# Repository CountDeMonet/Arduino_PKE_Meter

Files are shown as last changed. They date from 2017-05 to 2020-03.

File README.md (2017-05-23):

# Arduino_PKE_Meter
Code and models for an arduino based Ghostbusters PKE Meter

GBFans thread: http://www.gbfans.com/forum/viewtopic.php?f=5&t=43258

Video of how the meter looks when finished

https://www.youtube.com/watch?v=xTfZLYqommg

I have also included the eagle cad files that I used to produce an LED board for this project. OshPark is an amazing place to get custom PCB's fabricated and they will take the brd file as is. I ended up using a buck converter to power the servo so the path with the capacitor was no longer needed. That saved some space but the board was already in fab. 

Image of the internals
https://i1.wp.com/vineripesoftware.files.wordpress.com/2017/05/img_20170508_222438829.jpg

I recommend using hitec servo wire if you can get your hands on it for the wings. I printed everything at .3mm resolution with 20% infill. This print requires a lot of support and there is no way around it.

It's based off this model on Thingiverse (https://www.thingiverse.com/thing:700251) I scaled it up to 110%, removed a few buttons to make it easier to use for my son, and created a new battery holder for the 4 AAA's that power it. I decided on an Arduino nano as the brains with a cheap LCD for display. Again, not going for screen accurate but something that will keep a 6-7 year old entertained. I did program in the Ghostbusters 2 LED pattern for the wings.

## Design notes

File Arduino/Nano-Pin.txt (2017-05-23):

vin/gnd - to power
5v/gnd - to rail
A4 - SDA on Display
A5 - SLC on Display
D3 - Button 1
D4 - Button 2
D5 - Buzzer
D6 - LED 1
D7 - LED 2
D8 - LED 3
D9 - LED 4
D10 - LED 5
D11 - LED 6
D12 - LED 7
D13 - Servo Signal

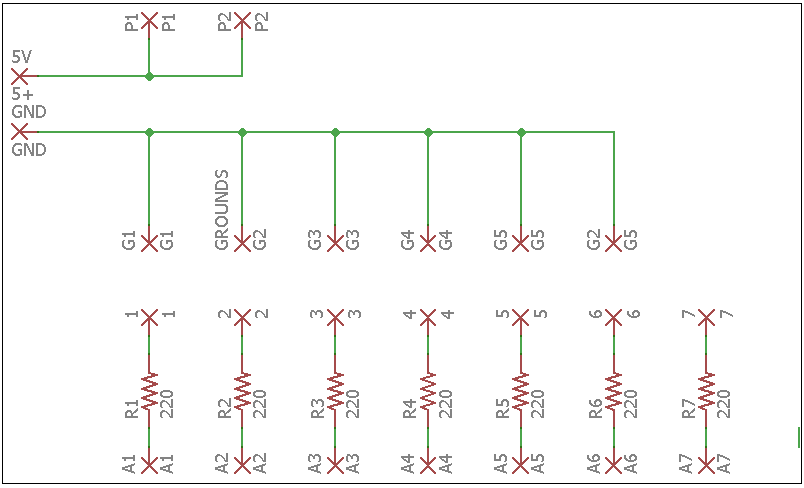
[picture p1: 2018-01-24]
Eagle/schematic.png

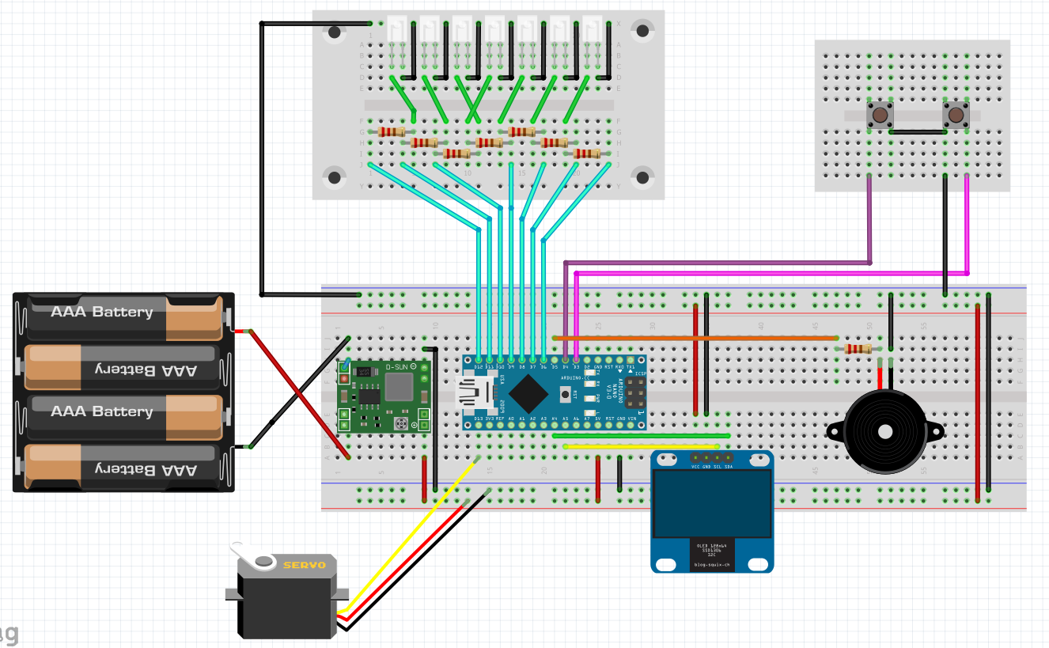
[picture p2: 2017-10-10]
PKE_Meter_Breadboard.png

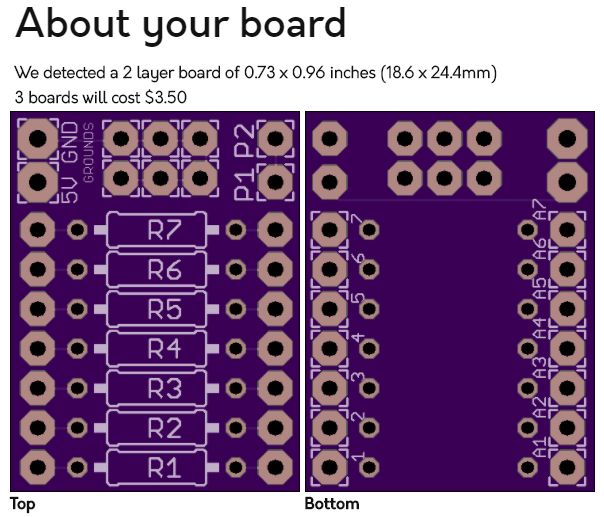
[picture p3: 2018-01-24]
Eagle/layout.png

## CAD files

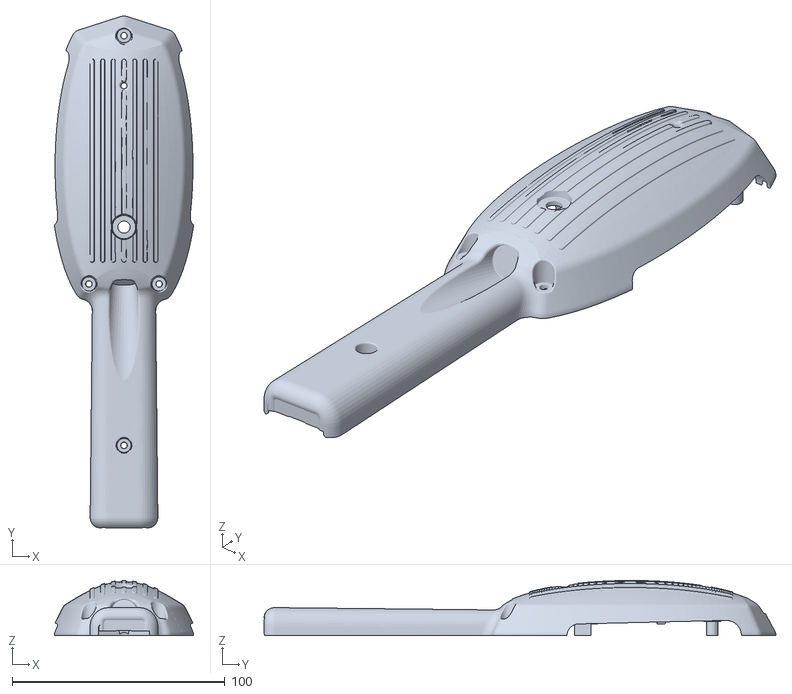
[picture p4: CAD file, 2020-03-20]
Model/back_one_piece.stl
65.5 x 240.6 x 25.9

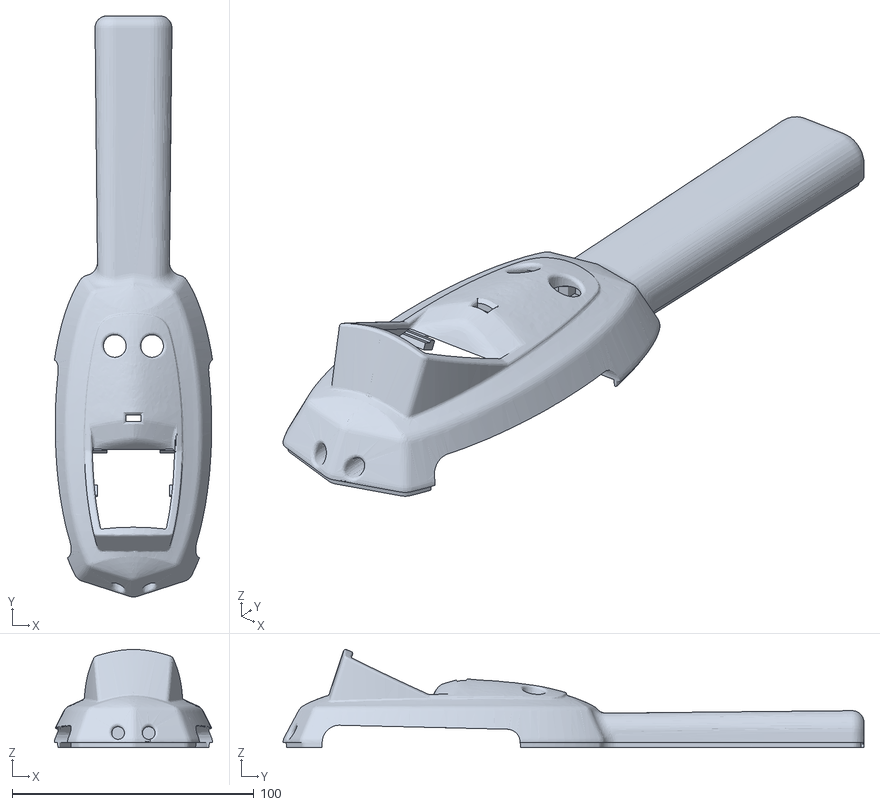
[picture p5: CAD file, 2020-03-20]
Model/front_one_piece.stl
65.5 x 240.5 x 40.6

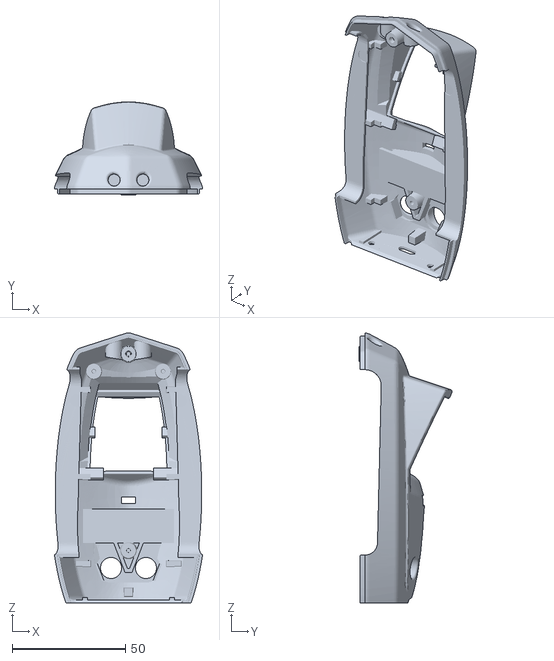
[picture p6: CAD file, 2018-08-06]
Model/front_top.stl
65.5 x 41.3 x 119.4

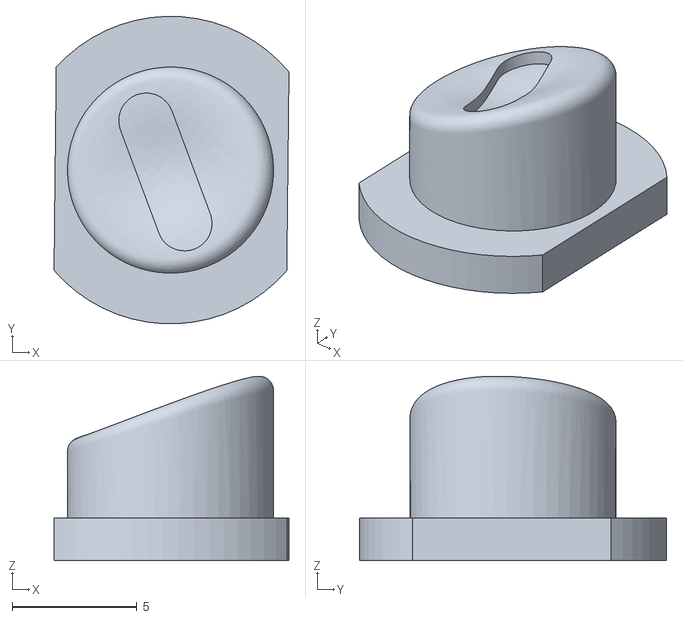
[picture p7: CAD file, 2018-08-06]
Model/buttons_filled.stl
9.41 x 12.3 x 7.39

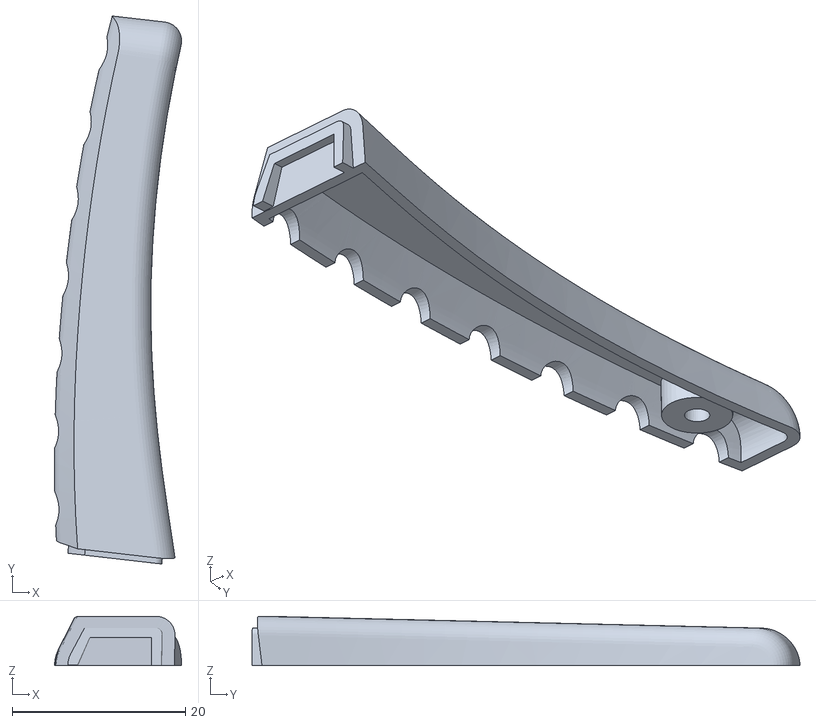
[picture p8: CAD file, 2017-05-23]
Model/wings_cover_right.stl
14.7 x 63.3 x 5.71

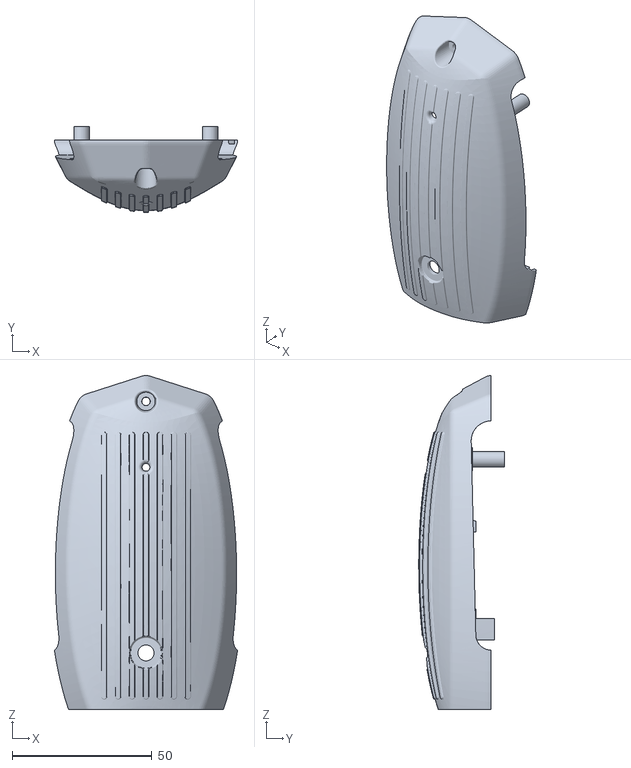
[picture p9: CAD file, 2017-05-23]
Model/back_top.stl
65.5 x 30.6 x 119.4

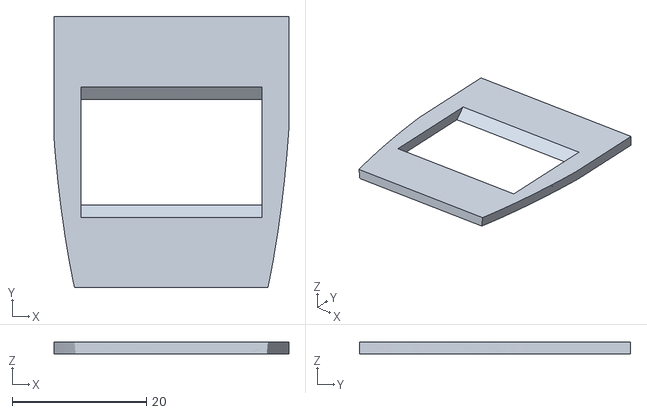
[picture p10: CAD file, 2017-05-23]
Model/screen_holder.stl
35.0 x 40.3 x 1.86

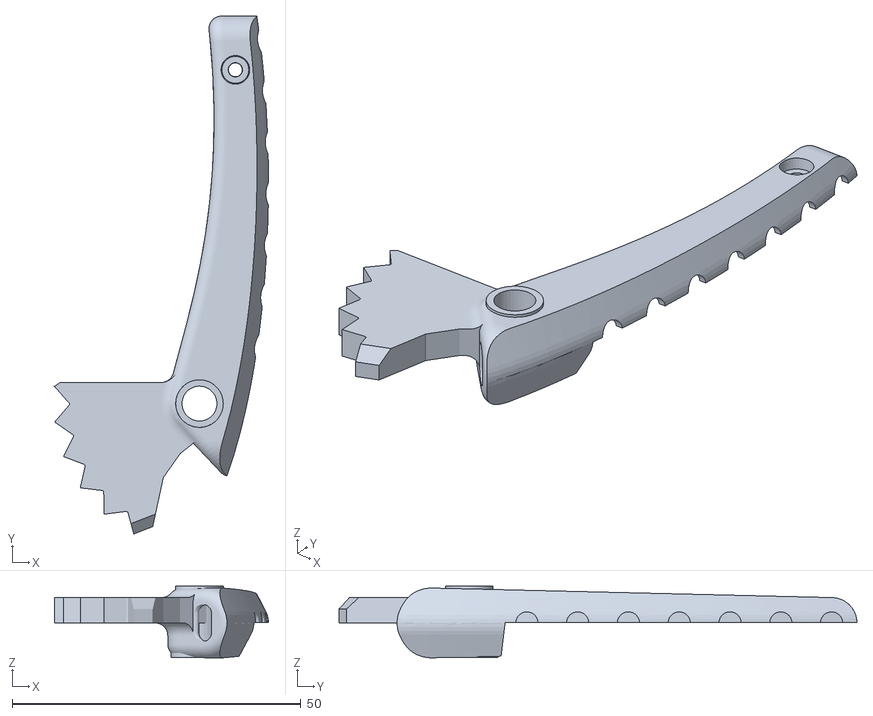
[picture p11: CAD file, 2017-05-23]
Model/wings_right.stl
37.1 x 89.8 x 12.4

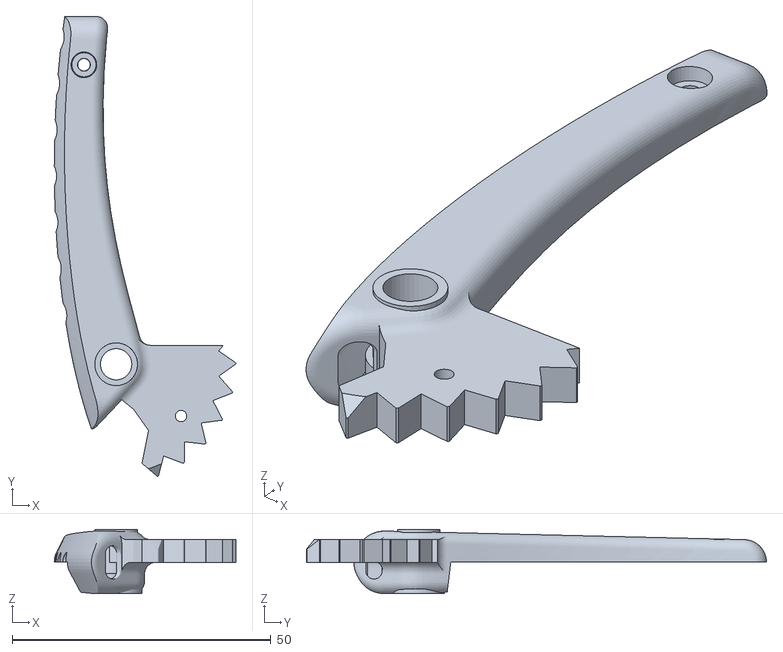
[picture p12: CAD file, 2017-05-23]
Model/wings_left.stl
35.1 x 88.8 x 12.4

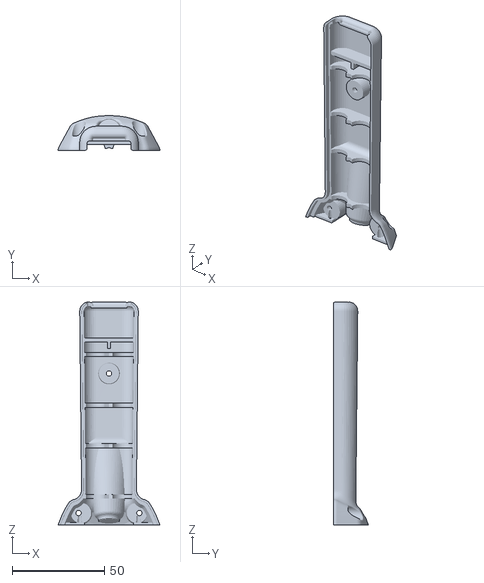
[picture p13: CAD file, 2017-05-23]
Model/back_bottom.stl
55.3 x 18.9 x 121.2

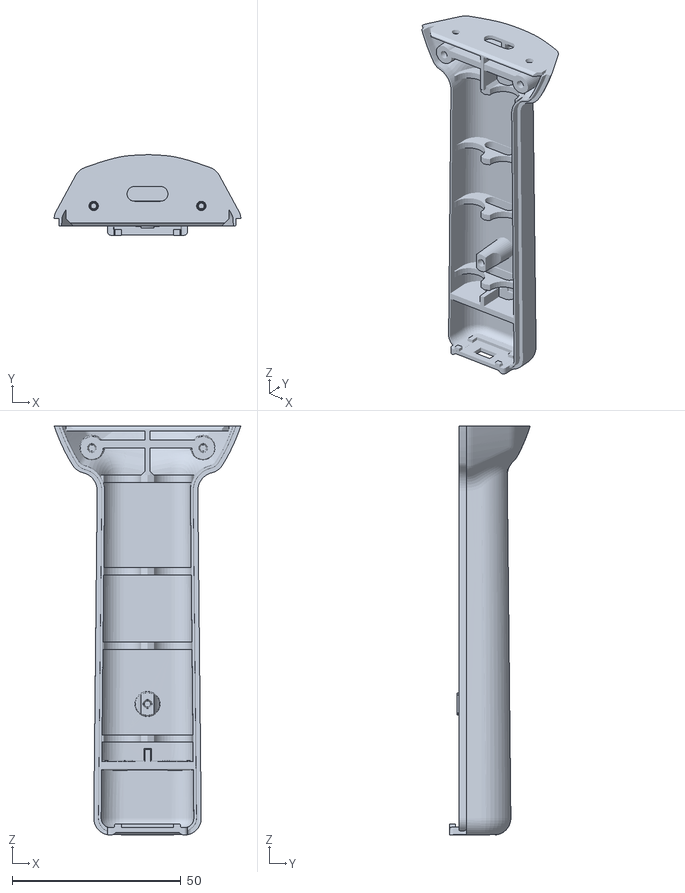
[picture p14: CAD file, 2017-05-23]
Model/front_bottom.stl
55.3 x 23.9 x 121.2

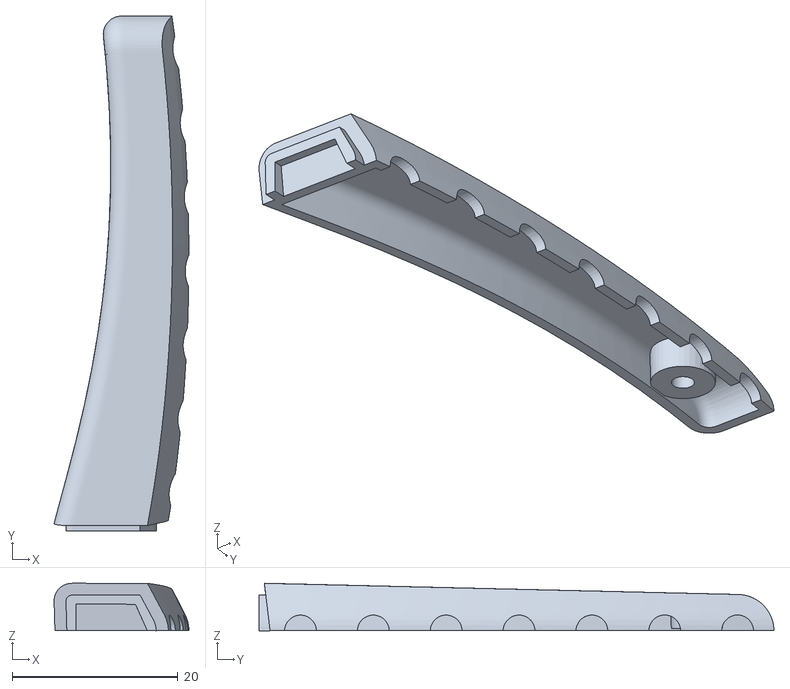
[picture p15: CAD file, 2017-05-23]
Model/wings_cover_left.stl
16.3 x 62.2 x 5.74

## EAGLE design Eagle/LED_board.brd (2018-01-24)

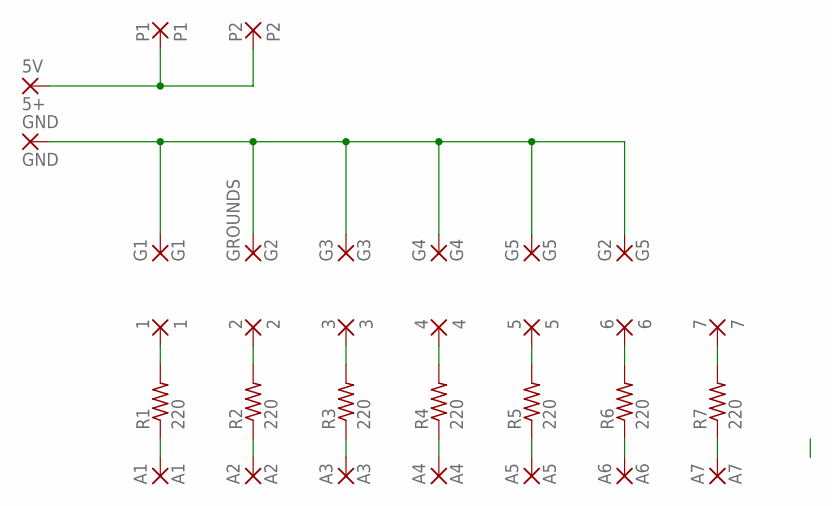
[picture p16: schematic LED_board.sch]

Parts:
1: 1; 2,15/1,0
2: 2; 2,15/1,0
3: 3; 2,15/1,0
4: 4; 2,15/1,0
5: 5; 2,15/1,0
5V: 5+; 2,54/1,1
6: 6; 2,15/1,0
7: 7; 2,15/1,0
A1: A1; 2,15/1,0
A2: A2; 2,15/1,0
A3: A3; 2,15/1,0
A4: A4; 2,15/1,0
A5: A5; 2,15/1,0
A6: A6; 2,15/1,0
A7: A7; 2,15/1,0
G1: G1; 2,15/1,0
G2, G5: G5; 2,15/1,0
G3: G3; 2,15/1,0
G4: G4; 2,15/1,0
GND: GND; 2,54/1,1
GROUNDS: G2; 2,15/1,0
P1: P1; 2,15/1,0
P2: P2; 2,15/1,0
R1, R2, R3, R4, R5, R6, R7: 220; 0207/10

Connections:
unnamed: 5V.1, P1.1, P2.1
unnamed: 1.1, R1.2
unnamed: A1.1, R1.1
unnamed: G1.1, G2.1, G3.1, G4.1, G5.1, GND.1, GROUNDS.1
unnamed: 2.1, R2.2
unnamed: A2.1, R2.1
unnamed: A3.1, R3.1
unnamed: 3.1, R3.2
unnamed: 4.1, R4.2
unnamed: A4.1, R4.1
unnamed: A5.1, R5.1
unnamed: 5.1, R5.2
unnamed: 6.1, R6.2
unnamed: A6.1, R6.1
unnamed: A7.1, R7.1
unnamed: 7.1, R7.2

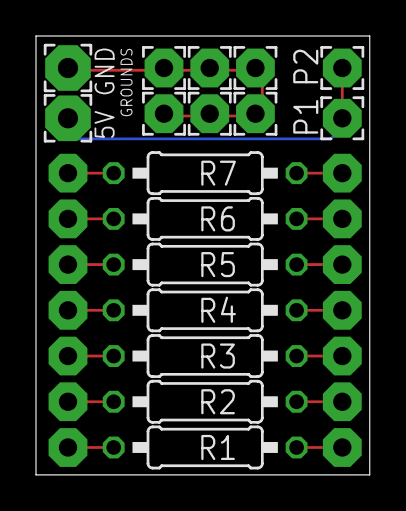
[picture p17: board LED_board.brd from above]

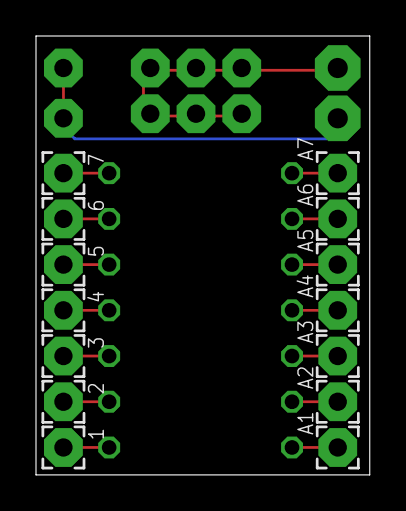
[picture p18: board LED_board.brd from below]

Board: 2 copper layers, 18.5 x 24.4 mm, 31 parts (14 on the bottom side), 16 nets.

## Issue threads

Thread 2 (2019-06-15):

OLED Image Scale Issue

MrBull-STR, 2019-06-15:
SEE Photo for reference.
The image appears
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
 to be scaled to fit another screen than 128x64.

CountDeMonet, 2019-06-17:
a user on gbfans is having the same issue. Are you using the library version that I have in the git repo here?

https://github.com/CountDeMonet/Arduino_PKE_Meter/tree/master/Arduino/libraries

The user on gbfans bought this led screen which the company seems to have designed their own library for. The docs say it works with the lib I use but who knows.

https://www.amazon.ca/gp/product/B01N78FUH7/ref=ppx_yo_dt_b_asin_title_o05_s00?ie=UTF8&psc=1

You may have to use their libs for things to work correctly. Try the adafruit example included in the arduino ide for the SSD1306

File -> Exampes -> Adadfruit SSD1306 -> ssd1306_128x64_ic2

if that one doesn't work properly then you'll have to do some work to figure out what's going on

CountDeMonet, 2019-07-17:
Seems this is coming up more often. DIYMall has a version of this display that appears to have a different resolution so some modifications and possibly use their library version.

This is from a doc linked from the diymall website

http://www.diymalls.com/IIC-OLED-SSD1306
https://drive.google.com/open?id=1qkexP ... 4F-JEKkrHZ

that document zip contains special versions of the adafruit libs
For 0.96 inch: 0.96 inch use SSD1306 drive chip. Copy "Adafruit_SSD1306.h" and
"Adafruit_GFX.h" into "x:\arduino-1.X.X\libraries".
In order to reduce the pins’ number, we use a hardware RESET system. So the
standard library form Adafruit or u8glib may not very suitable. Make sure you are
using our provided libraries, It’s very important. If those files already in you
libraries, replace it.
They also note
The dot matrix is 128 * 32
We never produced any 0.96 or 1.3 inch with 128*32 dot matrix. Open
“Adafruit_SSD1306.h”, and make sure the “#define SSD1306_128_64” is available.
Could be why you are seeing some strange things.

Closed 2020-02-02.

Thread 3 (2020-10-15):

Please add BOM

DarthBanana, 2020-10-15:
It would be great if you could add the bill of materials (parts list).

CountDeMonet, 2020-10-15:
Check the gbfans thread. it has all the info https://www.gbfans.com/forum/viewtopic.php?p=4893554#p4893554

DarthBanana, 2020-10-15:
Thanks for the quick reply!  That is very helpful.

________________________________
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

DarthBanana, 2020-10-15:
What about the battery contact plates?

CountDeMonet, 2020-10-15:
I don't really have a part for that. I think I scavenged something from one of my son's toys.

Closed 2020-10-25.

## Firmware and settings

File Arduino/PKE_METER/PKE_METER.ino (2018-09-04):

#include <Servo.h>
#include <Adafruit_GFX.h>
#include <Adafruit_SSD1306.h>

#define OLED_RESET 4
Adafruit_SSD1306 display(OLED_RESET);

Servo SERVO1;

int LEDNum = 0; // current LED that is lit
unsigned long previousMillis;   // will store last time LED was updated

const int LED1 = 12;
const int LED2 = 11;
const int LED3 = 10;
const int LED4 = 9;
const int LED5 = 8;
const int LED6 = 7;
const int LED7 = 6;

int FILM;
bool SOUND;

const int GB1_PATTERN[7] = {
  LED3, LED5, LED7, LED4, LED1, LED6, LED2
};
const int GB2_PATTERN[7] = {
  LED3, LED1, LED6, LED4, LED7, LED5, LED2
};

const int DISPLAY_PATTERN[][2] = {
  {21, 5},
  {18, 20},
  {15, 30},
  {12, 45},
  {9, 50},
  {6, 55},
  {3, 65}
};

const int BUZZER = 5;
const int BUTTON1 = 3;
const int BUTTON2 = 4;

// know thy button state
bool medium_state = false;
bool high_state = false;
bool button1_down = false;
bool button2_down = false;

void setup() {
  pinMode(LED1, OUTPUT);
  pinMode(LED2, OUTPUT);
  pinMode(LED3, OUTPUT);
  pinMode(LED4, OUTPUT);
  pinMode(LED5, OUTPUT);
  pinMode(LED6, OUTPUT);
  pinMode(LED7, OUTPUT);
  pinMode(BUZZER, OUTPUT);
  pinMode(BUTTON1, INPUT);
  pinMode(BUTTON2, INPUT);

  digitalWrite(BUTTON1, HIGH);
  digitalWrite(BUTTON2, HIGH);

  // The following lines are because my PKE setup
  // is currently running without the buck converter.
  // Pin D2 acts as VCC for the OLED screen
  // PN June 12, 2018d
  pinMode(2, OUTPUT);
  digitalWrite(2, HIGH);

  display.begin(SSD1306_SWITCHCAPVCC, 0x3C);
  display.display();

  // Clear the buffer.
  display.clearDisplay();
  initialSetup();

  SERVO1.attach(13);
  SERVO1.write(90);
}

// current display val
int currentVal = 0;
void loop() {
  int button1 = digitalRead(BUTTON1);
  int button2 = digitalRead(BUTTON2);

  if ( button1 == LOW && button1_down == false ) {
    button1_down = true;

    if ( medium_state == true) {
      medium_state = false;
      high_state = false;
      currentVal = 0;
    } else {
      medium_state = true;
      high_state = false;
      currentVal = 40;
    }
  } else {
    if (button1 == HIGH && button1_down == true ) {
      button1_down = false;
    }
  }

  if ( button2 == LOW && button2_down == false ) {
    button2_down = true;

    if (high_state == true) {
      medium_state = false;
      high_state = false;
      currentVal = 0;
    } else {
      medium_state = false;
      high_state = true;
      currentVal = 90;
    }
  } else {
    if (button2 == HIGH && button2_down == true ) {
      button2_down = false;
    }
  }

  // do the led stuff
  LEDLoop(currentVal);

  // do the servo stuff
  ServoLoop(currentVal);

  // delay in between reads for stability
  delay(1);
}

void initialSetup(){
  String headings[] = {"WHICH PATTERN?", "SOUNDS?"};
  String labels[][2] = {
    {"GB1", "GB2"},
    {"NO", "YES"}
  };
  for (int i = 0; i < 2; i++){
    int button1 = digitalRead(BUTTON1);
    int button2 = digitalRead(BUTTON2);
    while (button1 == HIGH && button2 == HIGH){
      display.setTextSize(1);
      display.setTextColor(WHITE);
      display.setCursor(22, 5);
      display.print(headings[i]);
      display.setCursor(10, 30);
      display.print(labels[i][0]);
      display.setCursor(100, 30);
      display.print(labels[i][1]);
      display.display();
      button1 = digitalRead(BUTTON1);
      button2 = digitalRead(BUTTON2);
    }
    if (button1 == LOW && i == 0){
      FILM = 1;
    } else if (button2 == LOW && i == 0){
      FILM = 2;
    } else if (button1 == LOW && i == 1) {
      SOUND = false;
    } else if (button2 == LOW && i == 1) {
      SOUND = true;
    }
    digitalWrite(BUTTON1, HIGH);
    digitalWrite(BUTTON2, HIGH);
    delay(500);
    display.clearDisplay();
  }
}

int prevB = 0;
void drawDisplay(int level, int bar) {
  display.setTextSize(1);
  display.setTextColor(WHITE);
  display.setCursor(29, 5);
  String display_str = String("GHOSTBUSTERS");
  display.print(display_str);

  int b1 = random(prevB, bar);
  int b2 = random(prevB, bar);
  int b3 = random(prevB, bar);
  int b4 = random(prevB, bar);
  int b5 = random(prevB / 2, bar / 2);
  int b6 = random(prevB / 2, bar / 2);
  prevB = bar;

  display.fillRect(2, display.height() - (5 + b1), 5, b1, WHITE);
  display.fillRect(10, display.height() - (5 + b2), 5, b2, WHITE);
  display.fillRect(18, display.height() - (5 + b5), 5, b5, WHITE);
  display.fillRect(display.width() - 23, display.height() - (5 + b6), 5, b6, WHITE);
  display.fillRect(display.width() - 15, display.height() - (5 + b4), 5, b4, WHITE);
  display.fillRect(display.width() - 7, display.height() - (5 + b3), 5, b3, WHITE);

  display.drawCircle(display.width() / 2, display.height() / 2 + 7, level, WHITE);

  display.display();
}

void clearLoop() {
  display.clearDisplay();
  prevB = 0;
}

void LEDLoop(int convertedVal) {
  unsigned long ledSpeed = map(convertedVal, 0, 100, 500, 20);

  // check to see if it's time to change the state of the LED
  unsigned long currentMillis = millis();

  if ((unsigned long)(currentMillis - previousMillis) >= ledSpeed)
  {
    previousMillis = millis();
    if (SOUND) {
      TriggerBuzzer();
    }
    if (FILM == 1){
      if (LEDNum == 0){
        clearLoop();
        digitalWrite(GB1_PATTERN[6], LOW);
      } else {
        digitalWrite(GB1_PATTERN[LEDNum - 1], LOW);
      }
      digitalWrite(GB1_PATTERN[LEDNum], HIGH);
    } else {
      if (LEDNum == 0){
        clearLoop();
        digitalWrite(GB2_PATTERN[6], LOW);
      } else {
        digitalWrite(GB2_PATTERN[LEDNum - 1], LOW);
      }
      digitalWrite(GB2_PATTERN[LEDNum], HIGH);      
    }
    drawDisplay(DISPLAY_PATTERN[LEDNum][0], DISPLAY_PATTERN[LEDNum][1]);
    LEDNum = (LEDNum + 1) % 7;
  }
}

void TriggerBuzzer() {
  tone(BUZZER, 2000); // Send 2KHz sound signal...
  delay(20);        // ...for 20 msec
  noTone(BUZZER);
}

void ServoLoop(int convertedVal) {
  int servoVal = map(convertedVal, 0, 100, 110, 40);
  SERVO1.write(servoVal);
}

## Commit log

2018-01-24 Changed the board design so it is cheaper at oshpark and no longer has the unused components
    [LED_board.brd, LED_board.sch]
2018-01-24 update schematic
2018-06-11 refactor for mutliple movie support
    Refactors code for looping
    Adds support for both GB1 and GB2 wing light patterns
    Adds setup screens to prompt for which pattern to use and whether to play sounds
2018-06-12 Adds comments for mystery pin
    D2 is acting as VCC for the OLED screen in my current setup running without the buck converter. This adds comments for lines I failed to comment earlier.
    [PKE_METER.ino]
2018-08-06 fix errors on front_top and buttons
    [buttons_filled.stl, front_top.stl]
2018-09-04 buttons were reversed on my build so fixed the code to match the schematic.
    [PKE_METER.ino]
2018-09-17 fritzing file for schematic
    [PKE_Metere.fzz]
2020-03-20 experimental one piece versions of the front and back. Printing now will see how well it comes out
    [back_one_piece.stl, front_one_piece.stl]
